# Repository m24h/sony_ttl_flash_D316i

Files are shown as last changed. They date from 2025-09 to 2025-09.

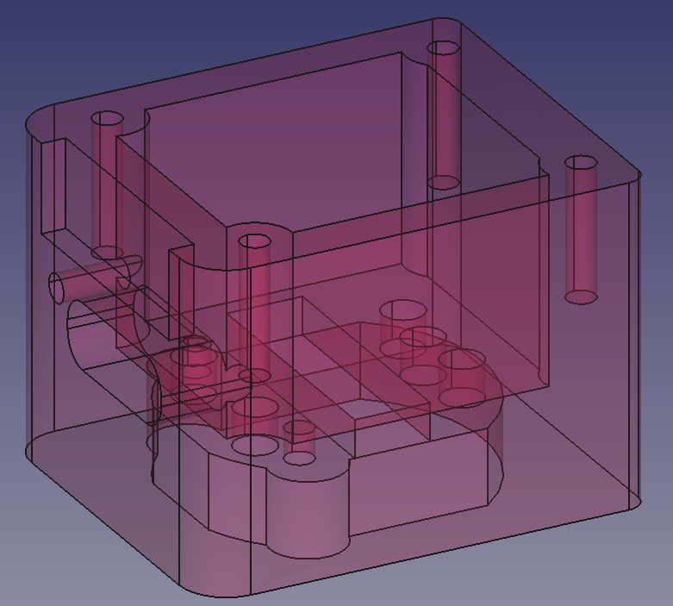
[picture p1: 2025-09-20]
parts/transfer.png

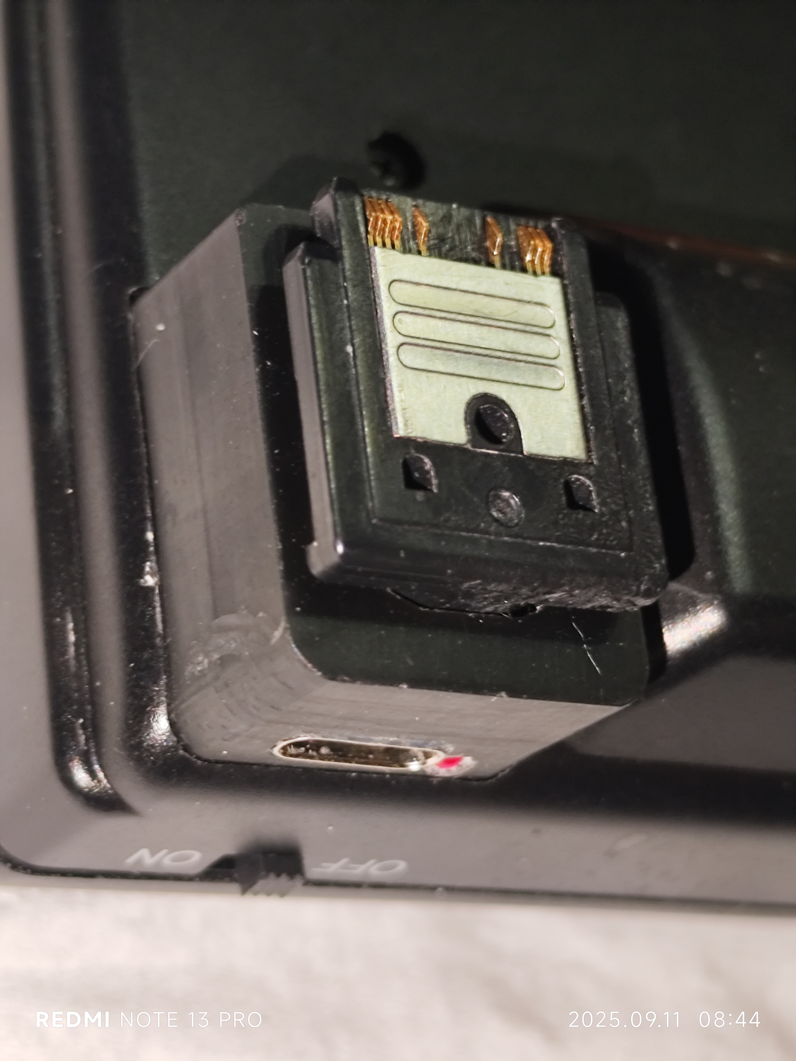
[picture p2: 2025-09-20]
practice/transfer.jpg

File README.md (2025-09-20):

# sony_ttl_flash_D316i

A Sony P-TTL flash built on a Minolta D316i body.

## About Minolta D316i

It is a compact flash, with a main capacitor of 280uF, and its Guide-Number is approximately 16. It is specifically designed for the Dynax/Maxxum 3000i, requiring no battery and using the power provided by the camera. It has a very rare and interesting design. After turning on the power, the flash pops out, which is said to be inspired by Ferrari.

## What has been modified

The shell and mechanical parts were retained, the circuit, circuit board, and program were newly designed, a lithium battery was added, 3D printed transfer adapter parts were made, and changed to Sony Multi-Interface.

## Sony P-TTL and some details

Based on the discussion at [Discovering the flash protocol (long)](https://www.dyxum.com/dforum/topic8297.html), with some of my own research added, the camera will interact with the flash, reading the maximum flash power of the flash, indicating to the flash to fire at an appropriate energy. For specifics, see flash_sony.h.
FEL is not supported because I don't think it's needed, but if support is desired, flash.c needs to be modified, changing FLASH_SONY_READ_FEATURE_DEF to FLASH_SONY_READ_FEATURE_DEF | FLASH_SONY_READ_FEATURE_NEW, and it will increase the workload of communication (which can still be easily handled).
During macro photography, the camera's pre-flash seems too strong, which can lead to an underestimation of the flash level. Therefore, some corrections were made algorithmically, see FLASH_LOW_FLASH_ENHANCE in flash.h/flash.c.
The compiler is SDCC v4.5, and the compiled binary file is main.bin, designed based on STC8H1K08 (base on 8051, but MCU needs to support rising edge triggered interrupts), and the burning details refer to readme.txt and STC8H1K08.cfg.
The flash time of the level (flash_time_of_level in main.c) is specially calibrated for my actual xenon tube, and may require recalibration on other tubes.
It's tested only on my A7CR camera.

## Pulseview

A sony flash protocol plug-in for pulseview is provided in directory pulseview. 

## Note

Frequent use of maximum power flash may damage IGBTs that do not have perfect cooling design.

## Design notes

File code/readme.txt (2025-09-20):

This program is for STC8H1K08 only.
Burning options:
- Run in 22.118400 MHz.	
- Reset pin (P5.4) used as I/O port.
- Disable Low-Voltage reset.
- Not to enable watch dog timer when power-on-reset
- watch dog timer stop count in idle mode

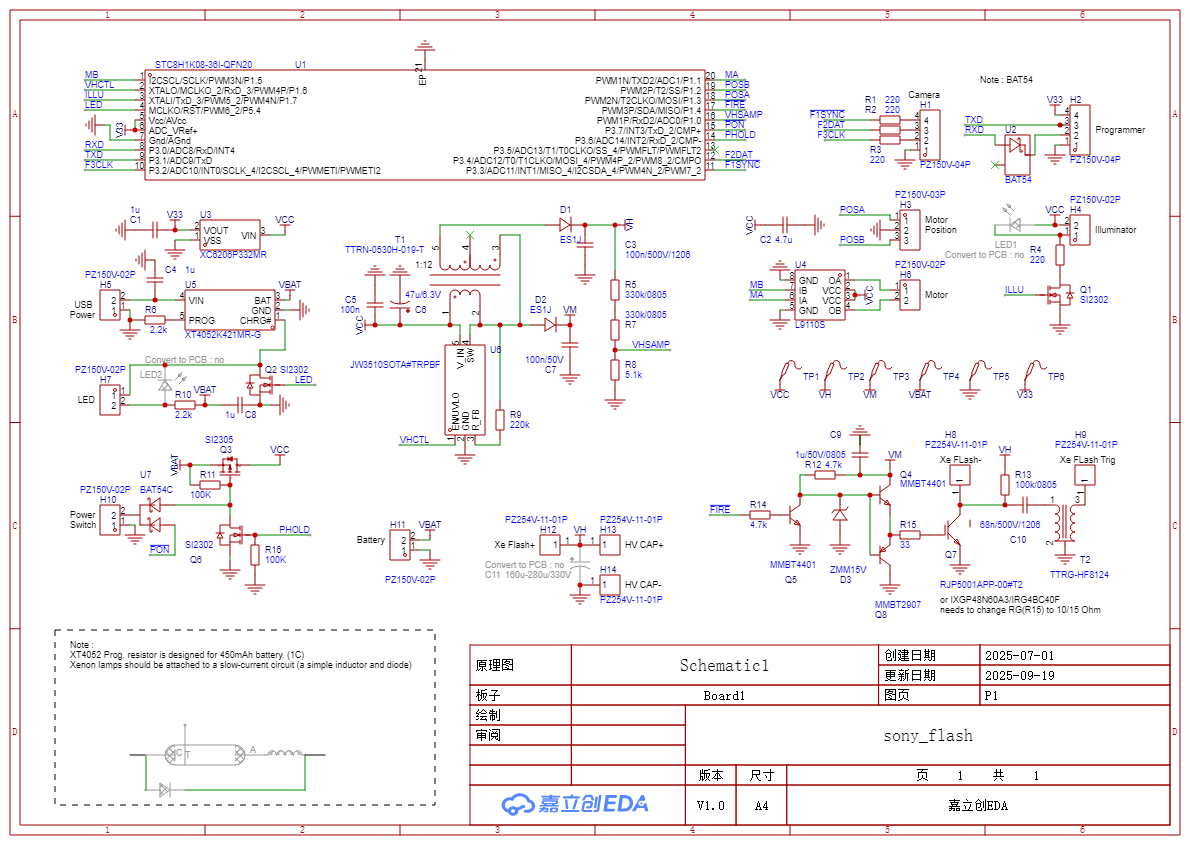
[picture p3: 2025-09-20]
circuit/sch.png

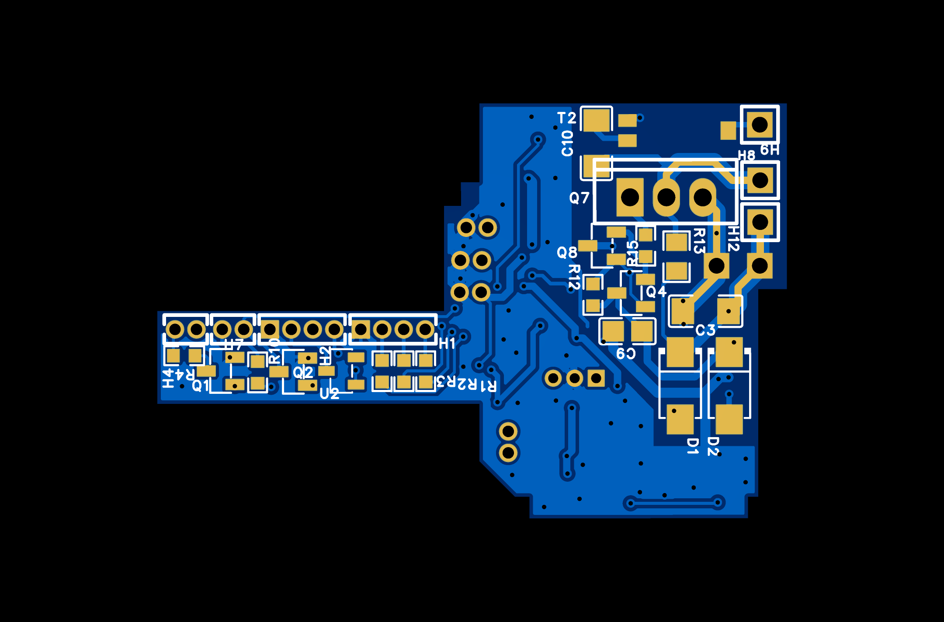
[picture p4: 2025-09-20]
circuit/2D_PCB1_bottom.png

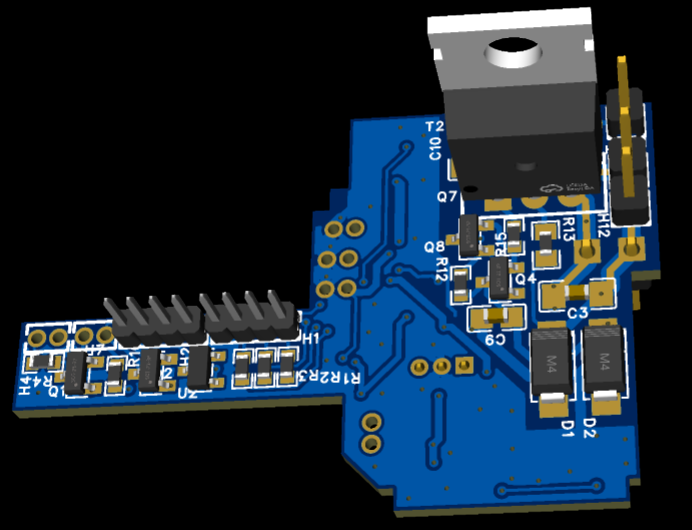
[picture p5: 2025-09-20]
circuit/3d-bottom.png

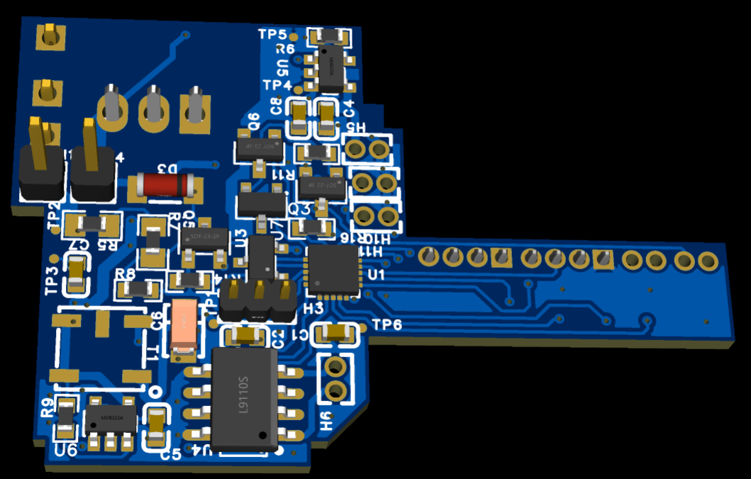
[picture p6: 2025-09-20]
circuit/3d-top.png

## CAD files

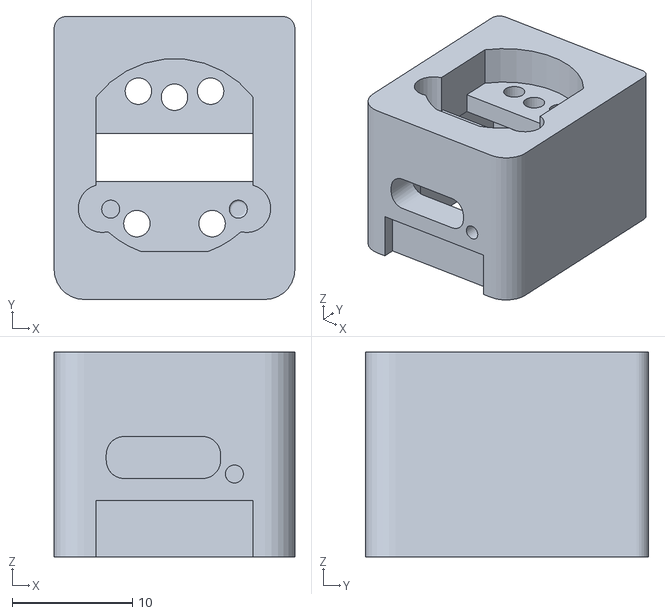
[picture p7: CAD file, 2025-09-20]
parts/transfer-Body.stl
20.0 x 23.5 x 17.0

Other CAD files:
parts/transfer.FCStd

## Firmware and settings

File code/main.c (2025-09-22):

#include "main.h"

#include "stc/mem.h"
#include "stc/pio.h"
#include "stc/tmr.h"
#include "stc/sys.h"
#include "stc/ser.h"
#include "stc/adc.h"
#include "flash.h"

/*
this is a small flash with small Xenon tube (GN16), so uses nearly a 1/8 full power (at flash_time_of_level[0]) as base/pre-flash power.
higher power levels are stable and easy to control and measure.
lower power levels appears unstable and not easy to control, requiring practical attempts to obtain specific flashing time.
*/
const uint16_t flash_time_of_level[64] = {
76,81,86,105,122,137,150,170,
196,251,340,580,1724,1959,1986,1986,
1986,1986,1986,1986,1986,1986,1986,1986,
1986,1986,1986,1986,1986,1986,1986,1986,
16,16,16,16,16,16,16,16,
22,23,23,24,25,25,26,27,
28,29,29,30,31,32,34,37,
41,45,49,53,56,61,66,72
};


uint16_t volt_vdd_mv = 3300;
uint16_t volt_high = 0;

// ADC ref voltage, normally 1190mV
static uint16_t adc_ref=1190;

#pragma save
#pragma disable_warning 126 // unreachable code by some setup macros
static void setup(void)
{
    sys_wdt_enable(1000, 0);
            
    // set ports (pins connected to camera are excluded)
    pio_disable_all();
    pio_reset(0);   // not to use reset pin
    pio_mclk(0, 0); // not to output sys clock
    P10=0;     pio_config(PIO_P10, PIO_ANALOG); // VHSAMP
    RXD=1;     pio_config(pio_pnn(RXD), PIO_BIDIR | PIO_SCHMITT); 
    TXD=1;     pio_config(pio_pnn(TXD), PIO_BIDIR | PIO_SCHMITT); 
    MA=0;      pio_config(pio_pnn(MA), PIO_OUTPUT); 
    MB=0;      pio_config(pio_pnn(MB), PIO_OUTPUT); 
    POSA_N=1;  pio_config(pio_pnn(POSA_N), PIO_BIDIR | PIO_SCHMITT); 
    POSB_N=1;  pio_config(pio_pnn(POSB_N), PIO_BIDIR | PIO_SCHMITT); 
    VHCTL=0;   pio_config(pio_pnn(VHCTL), PIO_OUTPUT); 
    ILLU=0;    pio_config(pio_pnn(ILLU), PIO_OUTPUT);
    LED=0;     pio_config(pio_pnn(LED), PIO_OUTPUT);
    PON_N=1;   pio_config(pio_pnn(PON_N), PIO_BIDIR | PIO_SCHMITT); 
    PHOLD=0;   pio_config(pio_pnn(PHOLD), PIO_OUTPUT);

    // serial port 1 as debug port
    ser1_setup(BAUDRATE, 1, SER1_P30P31, 0); // use timer 1 to drive it, not to use intr.
    debug(1, "Starting\n");
        
    // LVD level
    sys_lvd_setup(3000, 0, 0);
    
    // timer 2 ticks every 10ms, started, will raise intr.
    tmr2_setup_reload24(100, 1, 1, 0, 0);

    // setup ADC
    adc_setup(ADC_RATE, 0, 0); // not to raise intr.
    debug(1, "ADC Rate = %u kHz\n", (uint16_t)(adc_real_speed(ADC_RATE)/1000));
#ifdef ADC_REF_MV
    adc_ref = ADC_REF_MV;
#else
    adc_ref = adc_ref_mv();
    if (adc_ref<1000 || adc_ref>1300) adc_ref=1190; // maybe VRef is not writen into ROM, so use the default
#endif
    debug(1, "ADC Ref = %u mV\n", adc_ref);
}
#pragma restore

// timer 2 as system tick
static __data volatile uint16_t tick_10ms_isr = 0;
void tmr2_isr(void) __interrupt (TMR2_VECTOR) __naked
{
    // _tick_10ms_isr++
    __asm
    push    acc
    push    psw
    inc _tick_10ms_isr
    clr a
    cjne a, _tick_10ms_isr, 00010$
    inc (_tick_10ms_isr + 1)
00010$:
    pop psw
    pop acc
    reti
    __endasm;
}

uint16_t main_tick_get(void) __naked
{
    __asm
    anl _IE2, #(~ET2)
    nop
    nop
    mov dpl, (_tick_10ms_isr)
    mov dph, (_tick_10ms_isr+1)
    orl _IE2, #(ET2)
    ret
    __endasm;
}

static void shutdown(void)
{
    VHCTL = 0; // turn off high voltage
    ILLU=0;
    LED=0;
    FIRE_N=1;
    
    sys_delay_ms(50); // wait for IGBT driver power off (1uF & 4.7kOhm, tRC=4.7ms)
}

// main entry
void main(void)
{
    static __bit HV_disable = 0;
    
    EA = 0;
    nop();
    nop();
    mem_xram_enable();
    setup();
    flash_setup();
    EA = 1;
    
    // main loop
    while(1) {
        // feed the dog
        sys_wdt_clear();
        
        static uint16_t loops=0;
        ++loops;

        // on/off and motor/HV
        if ((PCON & LVDF) || PON_N) { // low voltage or switch off
            if (VHCTL) shutdown();
            if (POSB_N) { 
                MB = 1;
                MA = 0;
            } 
            else {
                sys_delay_ms(100); // wait for the mechanics to get more into place
                MB = 0;
                MA = 0;
                if (!POSB_N) { // check again
                    PHOLD = 0; // try to power off
                }
            }
            continue; // not to go donwn
        } else {
            if (!PHOLD) PHOLD = 1; // keep power on
            if (HV_disable) { // power is not turned on, maybe in DEBUG mode
                VHCTL = 0;
            } else if (!VHCTL) {
                if (volt_high<(uint16_t)(VH_DEST)-5) VHCTL=1;
            } else {
                /* Due to the leakage inductance of transformer, the HV is not the main negative feedback provider for the step-up power supply,
                   which may lead to excessively high voltage, so it needs to be shut down.
                   When flashing is needed, Sony will notify at least 10ms in advance, 
                   enough time (nealy 1ms tested) to restart the HV power supply,
                   and provide the driving power required by the IGBT. */
                register uint8_t t=flash_data.state; // flash_data.state maybe changed between multiple judgments
                if (t!=FLASH_SONY_COMM_FLASH0 && t!=FLASH_SONY_COMM_FLASH1 && t!=FLASH_SONY_COMM_SYNC
                	&& volt_high>(uint16_t)(VH_DEST)+5) {
                	VHCTL = 0;
                }
            }           
            if (POSA_N) { // turn up flash window
                MA = 1;
                MB = 0;
            } else if (MA) {
                sys_delay_ms(20); // wait for the mechanics to get into place
                MA = 0;
                MB = 0;
            }
        }

        //To speed up the cycle turnaround, the tasks are spreaded using task number, which should be at 1-255
        static __data uint8_t taskno = 0;
        ++taskno;
        if (taskno == 1) {
            // get device voltages
            uint16_t t16 = adc_get(ADC_VREF_CH);
            t16 = adc_get(ADC_VREF_CH); // double get to avoid cross-interference
            if (t16<=4096) t16 = adc_get(ADC_VREF_CH);
            if (t16<=4096) continue; // sometimes get 0, seems to be the "zero value" bug of STC ADC, many have encountered it too
            // adc_value/65536*Vdd = adc_ref
            // Vdd = adc_ref * 65536 / adc_value
            t16 = (uint16_t)((((uint32_t)adc_ref<<16)+(t16>>1))/t16);
            t16 = ((volt_vdd_mv<<1)+volt_vdd_mv+t16+2)>>2; // a simple filter
            EA = 0; // guarantee actomic data
            nop();
            nop();
            volt_vdd_mv=t16;
            EA = 1;
        } else if (taskno == 2) {
            // get high voltage
            uint16_t t16 = adc_get(ADC_VHSAMP_CH);
            t16 = adc_get(ADC_VHSAMP_CH); // double get to avoid cross-interference
            if (t16<=4096) t16 = adc_get(ADC_VHSAMP_CH);
            if (t16<=4096) continue; // sometimes get 0 or noises, seems to be the "zero value" bug of STC ADC, many have encountered it too
            // adc_value/65536*volt_vdd_mv/1000 = volt_high*VH_RATIO+VH_BIAS
            // volt_high = (adc_value/65536*volt_vdd_mv/1000 - VH_BIAS)/VH_RATIO
            // volt_high = (1049*(adc_value/64)*volt_vdd_mv/65536 - VH_BIAS*16384)*(4/VH_RATIO)/65536
            t16 = (1049UL*volt_vdd_mv*(t16>>6)+32768)>>16;
            t16 = t16>(uint32_t)(VH_BIAS*16384) ? ((t16-(uint32_t)(VH_BIAS*16384))*(uint32_t)(4/VH_RATIO)+32768)>>16 : 0;
            t16 = ((volt_high<<1)+volt_high+t16+2)>>2; // a simple filter
            EA = 0; // guarantee actomic data
            nop();
            nop();
            volt_high = t16;
            EA = 1;
        } else if (taskno == 3) {
            // show LED
            if (VHCTL && volt_high<(uint16_t)(VH_LEAST)) {
            	flash_can_fire = 0;
            	LED = (uint8_t)main_tick_get() & 0x10;
            } else {
            	flash_can_fire = 1;
            	LED = 1;
            } 
            // just play with illuminator
            ILLU = !(flash_data.write.func5 & FLASH_SONY_WRITE_FUNC5_NO_AF) && flash_data.state!=FLASH_SONY_COMM_OFFLINE;
        } else if (taskno == 4) {
            // incoming message (1 byte only) from default serial port
            switch ((unsigned char)tolower(getchar())) {
                case 'b': printf("SP = %x, ticks = %u, loops=%u\n", SP, main_tick_get(), loops);
                          break;
                case 'd': shutdown();
                          pio_disable_all(); 
                          sys_boot_ISP();
                          break;
                case 'r': shutdown();
                          pio_disable_all();
                          sys_boot();
                          break;
                case 'a': printf("VHCTL = %u, VDD = %u mV, VH = %u V\n", VHCTL, volt_vdd_mv, volt_high);
                          break;
                case 'p': printf("PON_N = %u, PHOLD = %u, VHCTL = %u, LVD=%u\n", PON_N, PHOLD, VHCTL, PCON & LVDF);
                          printf("ILLU = %u, LED = %u\n", ILLU, LED);
                          printf("MA = %u, MB = %u, POSA_N = %u, POSB_N = %u\n", MA, MB, POSA_N, POSB_N);
                          printf("F1SYNC = %u, F2DAT = %u, F3CLK = %u, FIRE_N = %u\n", FLASH_F1SYNC, FLASH_F2DAT, FLASH_F3CLK, FLASH_FIRE_N);
                          break;
                case 'c': PON_N = 0;
                          PHOLD = 1;
                          VHCTL = 0;
                          HV_disable = 1;
                          sys_delay_ms(1);
                          printf("PON_N = %u, PHOLD = %u, VHCTL = %u\n", PON_N, PHOLD, VHCTL);
                          break;
                case 'x': PON_N=1;
                          PHOLD = 0;
                          VHCTL = 0;
                          HV_disable = 0;
                          sys_delay_ms(1);
                          printf("PON_N = %u, PHOLD = %u, VHCTL = %u\n", PON_N, PHOLD, VHCTL);
                          break;
                case 'f': VHCTL = 1;
                          sys_delay_ms(10);
                          FIRE_N=0;
                          sys_delay_us(30);
                          FIRE_N=1;
                          sys_delay_ms(20);
                          FIRE_N=0;
                          sys_delay_us(100);
                          FIRE_N=1;
                          VHCTL = 0;
                          break;
                case 'i': ILLU=!ILLU;
                          sys_delay_ms(1);
                          printf("ILLU = %u, LED = %u\n", ILLU, LED);
                          break;
                case 's': printf("Sony read : ");
                		  for (uint8_t i=0; i<flash_data.rlen; i++) printf("%x ", flash_data.rbytes[i]);
                		  printf("\nSony write : ");
                		  for (uint8_t i=0; i<flash_data.wlen; i++) printf("%x ", flash_data.wbytes[i]);
                		  printf("\nPower pre=%d formal=%d\n", flash_power_pre, flash_power_formal);
                          printf("Actual pre=%d formal=%d\n", flash_power_pre_act, flash_power_formal_act);
                          break;
                case 'm': static int8_t power=-12;
                          power++;
                          if (power>FLASH_LEVEL_FULL) power=-12;
                          flash_data.read.mode &= ~FLASH_SONY_READ_MODE_CONTROLLED; // manual mode
                          flash_data.read.power = ((FLASH_POWER_LEVEL_MAX-power)<<2)+15;
                          printf("Manual mode, power=%d\n", power);
						  break;
                case '?': printf("bdrapcxfi\n");
                          break;
            } 
        }  else taskno = 0;
    }
} 

void flash_prepare(void) __using(FLASH_ISR_BANK)
{
	VHCTL = 1; // needs to turn on HV for IGBT driver
}

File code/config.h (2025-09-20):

// lib config, do not change these if hardware is not changed
#define MCU_STC8H1K08
#define FOSC 22118400

// ports config, do not change these if hardware is not changed
#define MA     P11
#define MB     P15
#define POSA_N P13
#define POSB_N P12
#define VHCTL  P16
#define ILLU   P17
#define LED    P54
#define FIRE_N P14
#define PON_N  P37
#define PHOLD  P36
#define RXD    P30
#define TXD    P31
#define ADC_VHSAMP_CH 0 // ADC channel

// flash config
#define FLASH_F1SYNC    P33
#define FLASH_F2DAT     P34
#define FLASH_F3CLK     P32
#define FLASH_FIRE_N    P14
#define FLASH_LEVEL_FULL 12 // GN16
#define FLASH_LOW_FLASH_ENHANCE

// main config
#define DEBUG       2       // debug level, 0 means no debug
#define BAUDRATE    9600

/*
V_sample = V_high * VH_RATIO + VH_BIAS, if VHCTL==1
*/
#define VH_RATIO     (5.1/665.1)
#define VH_BIAS      0
#define VH_LEAST     280     // 260V is the lowest fire voltage, but for P-TTL (double flash), 280V seems to be more stable
#define VH_DEST      300
#define ADC_RATE     100000  // 10us each time
#define ADC_REF_MV   1190

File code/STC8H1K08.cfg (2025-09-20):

[STC]
Version=V6.95U
McuType=STC8H1K08
Option=BFFCF7FFFFFFFFFFFFFFFFFFFFFFEDFF93
Frequency=22.1184
AutoReload=1
SoundTip=3
U8WVcc=0
U8WOnLinePower=1
U8WAdcMin=5
U8WAdcMax=15
SelfDefineEnable=1
SelfDefineBaud=9600
SelfDefineFormat=0
SelfDefineSize=1
SelfDefineStcDefault=0
SelfDefineCommand=6464
SelfDefineRTS=0
SelfDefineDTR=0
